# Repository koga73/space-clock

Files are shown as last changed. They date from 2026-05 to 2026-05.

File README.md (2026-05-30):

INTRODUCING THE

# SPACE CLOCK

ALWAYS RIGHT. AUTOMAGICALLY.

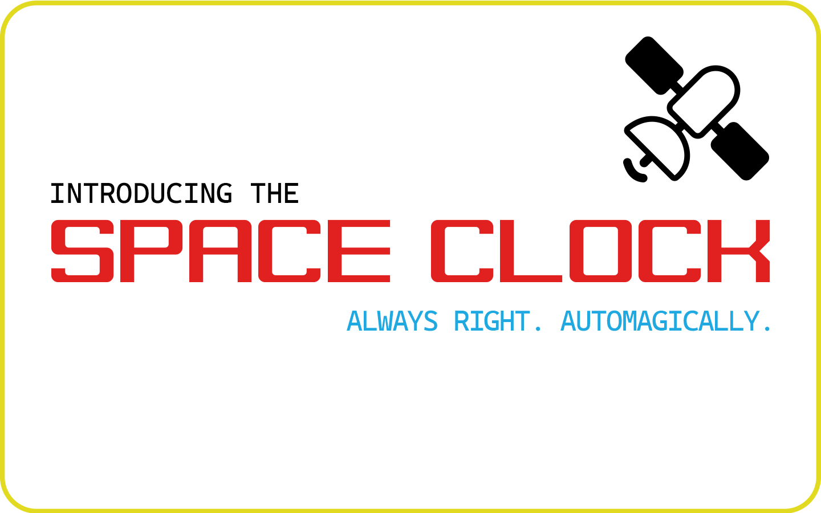
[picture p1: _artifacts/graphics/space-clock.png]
SPACE CLOCK graphic


## What is the SPACE CLOCK ?

The SPACE CLOCK sets itself using GPS signals to achieve microsecond accuracy of up to one millionth of a second. Not only is the SPACE CLOCK a physical clock, but it also acts as an __NTP__ server (network time server) allowing you to sync precise time across all of your network devices.

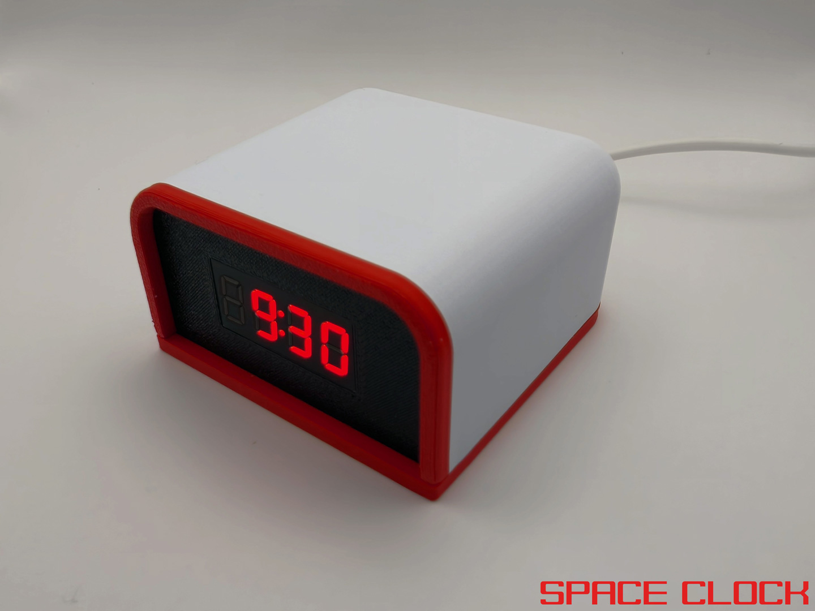
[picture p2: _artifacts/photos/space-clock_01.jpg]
SPACE CLOCK photo


## Features

- Captures `PPS (Pulse Per Second)` signal from `GPS satellites` which marks the exact start of a second
- Parses `GPS NEMA` sentences which contain data including `UTC Time`, Latitude / Longitude and more
- Built-in `NTP Server` for syncing network time
- `Web interface` with status page and configuration options __(24-hour Format, Timezone, Daylight Savings)__
- WiFi AP mode broadcasts a `hotspot` with web interface to `connect to nearby WiFi` networks
- Open-source firmware, schematics, and space-age 3D printable case

### Bill of Materials

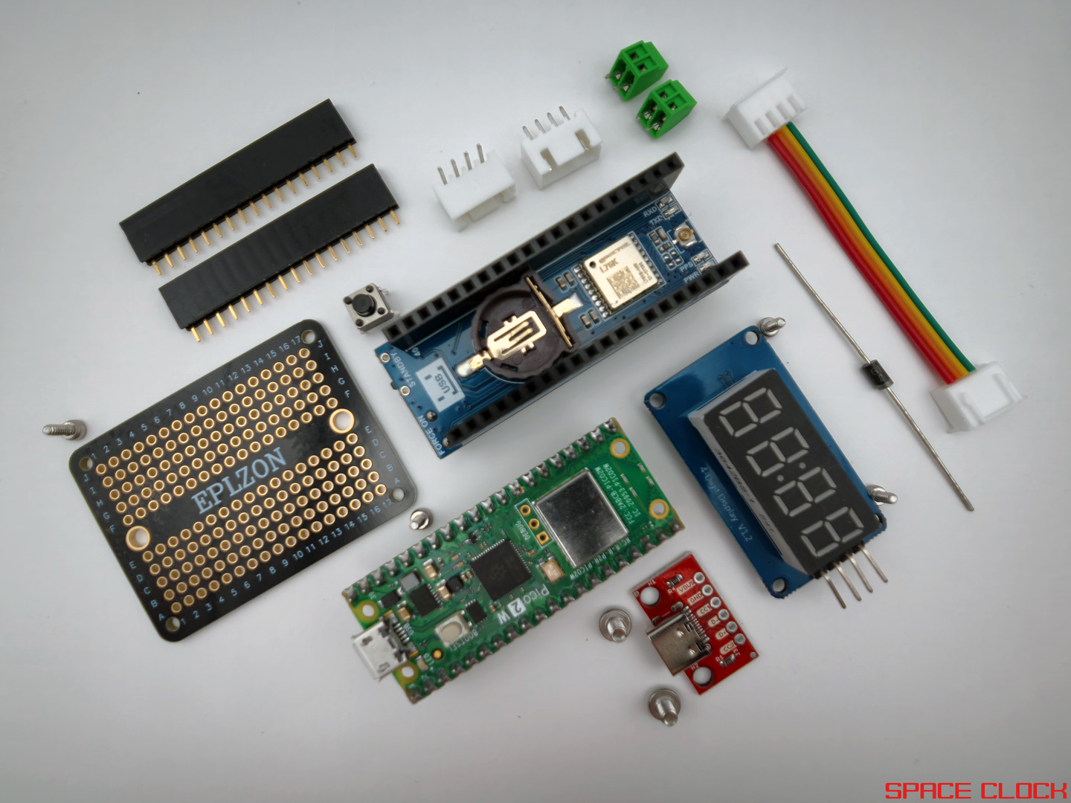
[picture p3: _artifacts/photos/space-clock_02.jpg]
SPACE CLOCK bill of materials


- [Raspberry Pi Pico 2 W](https://www.raspberrypi.com/products/raspberry-pi-pico-2/)
- [Waveshare L76K GPS module](https://www.waveshare.com/pico-gps-l76k.htm)
- [4-Digit 7-Segment display](https://www.amazon.com//dp/B0BFQNFX6D/)
- [USB-C breakout board](https://www.amazon.com/dp/B0BLSN5PR8/)
- [Solderable breadboard mini](https://www.amazon.com/dp/B09WZY8CFV/)
- [Tactile button 6x6x5mm](https://www.amazon.com/dp/B01CGMP9GY/)
- [Schottky diode 1N5817](https://www.amazon.com/dp/B07Q5H1SLY/)
- [Female headers](https://www.amazon.com/dp/B0GM834DC8/)
- [M2x4mm screws](https://www.amazon.com/dp/B0DCKDF1PD/)
- [M3x4mm screws](https://www.amazon.com/dp/B08H24W42K/)

#### Optional for GPS

- [GPS antenna](https://www.amazon.com/dp/B07Y6D76G9/) for housing internally
- [ML1220 li-ion battery](https://www.amazon.com/dp/B088KT9HB9/) for preserving ephemeris information and hot starts

## Modes

The SPACE CLOCK can operate in modes with or without a WiFi connection.

### No WiFi

First boot and when no WiFi credentials are present will simply show the current time.

1. Power via USB-C, will display `----`
2. GPS to process UTC time, will display `rising / falling animation`

> To connect to WiFI hold the bottom button for 3 seconds to reboot into AP Mode

### WiFi Mode

If WiFi credentials are available it will attempt to connect, start web/ntp servers and then display the current time.

> If WiFi fails to connect the device will reboot

1. Power via USB-C, will display `----`
2. Connect to saved wifi, will display `wave animation`
3. Successful WiFi connection will display `IP address` once
4. Start servers for web interface and ntp
5. GPS to process UTC time, will display `rising / falling animation`

> You can view the [status page](http://{IP_ADDRESS}/status) when connected via _WiFi Mode_

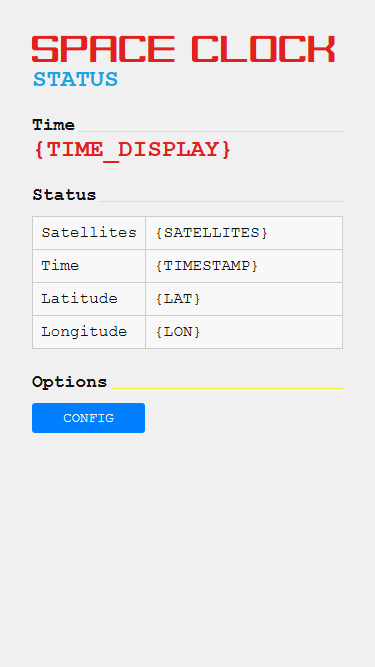
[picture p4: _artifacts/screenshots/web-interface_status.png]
SPACE CLOCK screenshot status


### AP Mode

1. Power via USB-C, will display `----`
2. Scan for nearby networks, will display `SCAN`
3. Start the AP hotspot, will display the hotspot name and start the web server
4. __You connect to the hotspot__ (`space_clock`)
5. __You navigate to the default gateway__ (http://192.168.4.1)
6. A webpage will load showing nearby WiFi networks
7. __You select a WiFi network and enter its password__
8. Device will reboot into _WiFi Mode_

> You can view the [connect to wifi page](http://192.168.4.1/connect) when connected via _AP Mode_

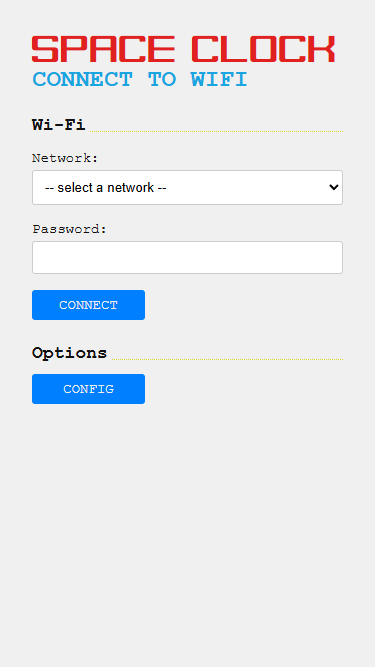
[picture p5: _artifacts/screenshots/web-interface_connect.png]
SPACE CLOCK screenshot connect


## Configuration

The SPACE CLOCK operates on UTC Time and uses the following localized defaults which can be changed:

- __24-hour format__: False
- __Timezone__: (GMT-05:00) America/New_York
- __Daylight Savings__: US/CA

> You can change these settings through the [configuration page](http://192.168.4.1/config) when connected via _WiFi Mode_ or _AP Mode_

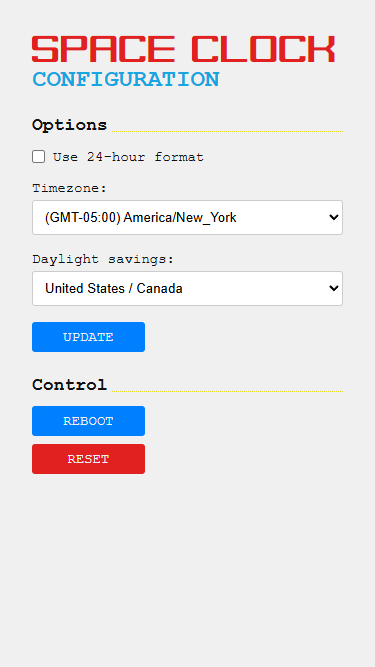
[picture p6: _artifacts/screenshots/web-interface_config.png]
SPACE CLOCK screenshot config


### 24-hour format

The SPACE CLOCK supports displaying localized time in either __12-hour AM/PM format__ or __24-hour GMT/Military format__

#### Button to change hour format

To quickly change between 12-hour / 24-hour formats just press the bottom button once

#### Web interface to change hour format

You can change this setting and more through the web interface when connected via _WiFi Mode_ or _AP Mode_.

### Timezone

GPS satellites transmit time in UTC, as such you can change the localized timezone.

#### Web interface to change TZ

_Timezone_ can be set through the following selections in the web interface:

- (GMT-10:00) Pacific / Honolulu
- (GMT-09:00) America / Anchorage
- (GMT-08:00) America / Los_Angeles
- (GMT-07:00) America / Denver
- (GMT-06:00) America / Chicago
- (GMT-05:00) America / New_York
- (GMT-03:00) America / Sao_Paulo
- (GMT+00:00) UTC / Europe / London
- (GMT+01:00) Europe / Paris
- (GMT+02:00) Africa / Cairo
- (GMT+04:00) Asia / Dubai
- (GMT+09:00) Asia / Tokyo
- (GMT+10:00) Australia / Sydney
- (GMT+12:00) Pacific / Auckland

### Daylight savings

GPS satellites transmit time in UTC, as such you can apply Daylight Savings with regional rules.

#### Web interface to change DST

_Daylight Savings_ rules can be applied through the following selections in the web interface:

- __United States / Canada__
	- Starts on second Sunday of March at 2am
	- Ends on first Sunday of November at 2AM
- __United Kingdom / European Union__
	- Starts on last Sunday of March at 1AM
	- Ends on last Sunday of October at 2AM
- __Australia__
	- Starts on first Sunday of October at 2am
	- Ends on first Sunday of April at 3AM

### Reboot

You can reboot the device by clicking the "__Reboot__" button in the web interface.

### Reset

You can factory reset the device by clicking the "__Reset__" button in the web interface. This will delete your preferences and reset the device back to defaults.

## Build your own!

This project can be built for around ~$50 at the time of writing

### Schematic

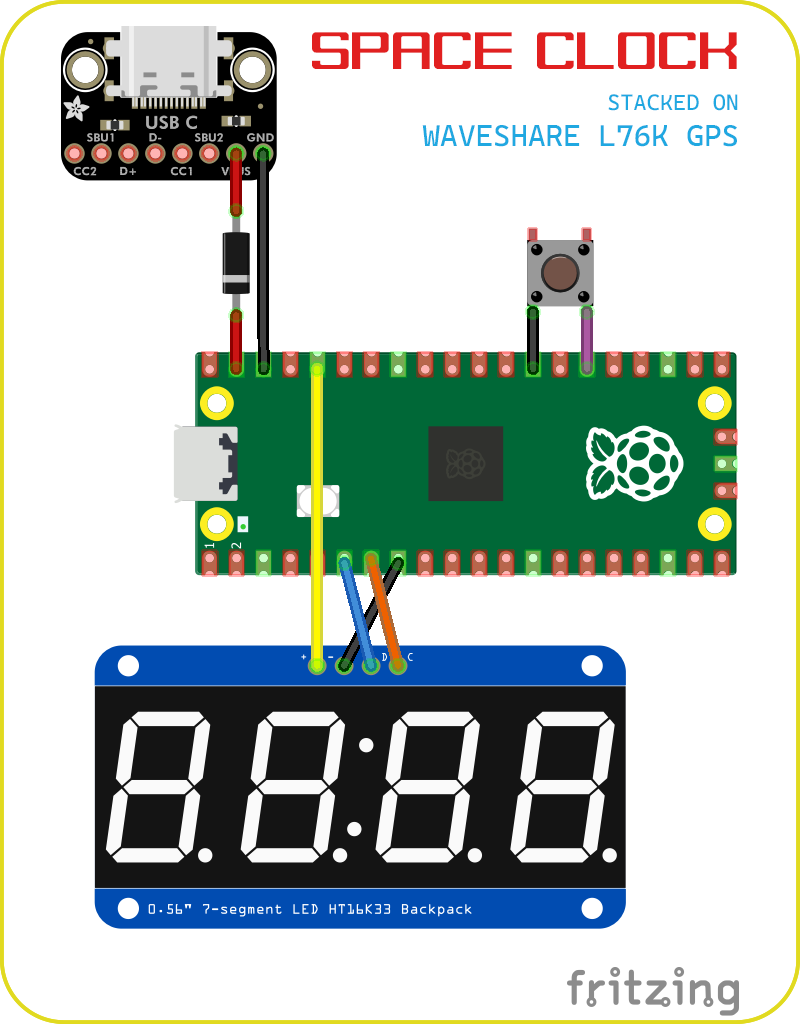
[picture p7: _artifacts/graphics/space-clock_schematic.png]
SPACE CLOCK schematic


### Enable PPS on the Waveshare L76K

For the most accurate time, there is a small modification needed to the _Waveshare L76K_ board which enables a PPS (Pulse Per Second) signal interrupt on `Pin 16`.

Follow the directions included in Waveshare's documentation, but essentially on the back of the board you just need to solder a `0Ω ohm resistor` or wire across the pads for `R20`.

### Raspberry Pi Pico 2 W

The firmware is written in MicroPython, as such you will need to follow the [instructions on flashing the MicroPython](https://www.raspberrypi.com/documentation/microcontrollers/micropython.html#what-is-micropython) runtime.

Then follow the guide to [Install dependencies and official VSCode extension](https://www.raspberrypi.com/news/get-started-with-raspberry-pi-pico-series-and-vs-code/)

To upload the code to the Pico through VSCode just open the command palette (CTRL + SHIFT + P) and select `MicroPico: Upload project to Pico`

### Power via USB-C breakout board

I wanted the ability to power the Pico via a USB-C breakout board and it was easy enough. Just connect the VBUS/VCC + GND on the breakout board to VSYS on the Pico `Pin 39` and GND to `Pin 38`

> You should put a Schottky Diode between external power and VSYS to prevent issues if powered via Micro-USB and Externally at the same time

### Display

Since this is a clock, the good ole 4-digit 7-segment display makes sense!

Wiring:
- Display GND to Pico GND `Pin 8`
- Display VCC to Pico 3v3(OUT) `Pin 36`
- Display DIO to Pico I2C0 SDA `Pin 6`
- Display CLK to Pico I2C0 SCL `Pin 7`

> On my solderable breadboard I connected row 36 with row 5. On the female header I removed the pin on row 5. This allows for the 3V3(OUT) to be next to the other pins 6/7/8 needed for display.

### Button

The button on the bottom allows for short presses such as to change between 12-hour / 24-hour format as well as long holds to toggle reboot of modes WiFi / AP

One leg of the button should go to GND `Pin 13` / `Pin 28` and the other leg should attach to GP20 `Pin 26`

### 3D printed case

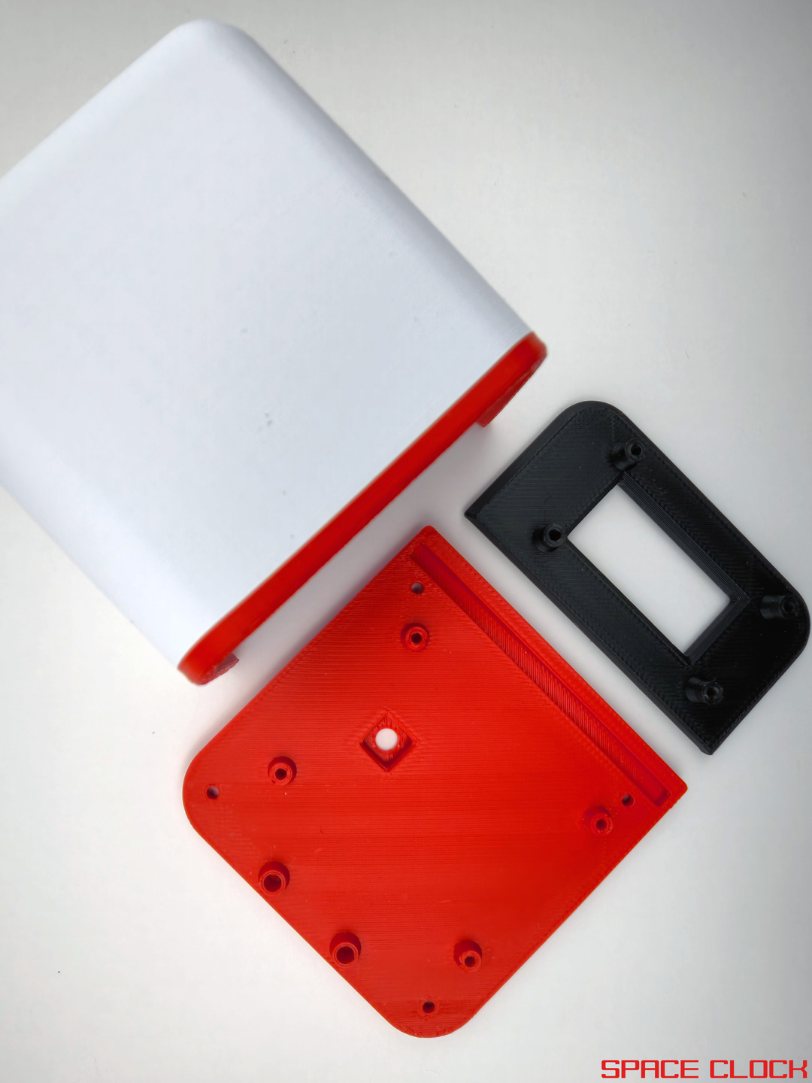
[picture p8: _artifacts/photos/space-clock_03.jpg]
SPACE CLOCK 3d printed case


The case consists of three parts, the display mount, the bottom plate and the top cover.

- Print in PLA with or without infill.
- Print top cover vertically with support

Use the appropriate M2/M3 screws listed in the bill-of-materials to mount the boards to the respective case pieces.

#### SMA connector

Inside the case cover is a pre-formed 0.25in cutout for an SMA connector if you want an external GPS antenna just can drill this out with a 0.25in forstner drill bit.

If you do not want an external GPS antenna you can place a small ceramic GPS antenna internally. I stuck mine to the backside of the female headers with 3M VHB tape.

### Assembly

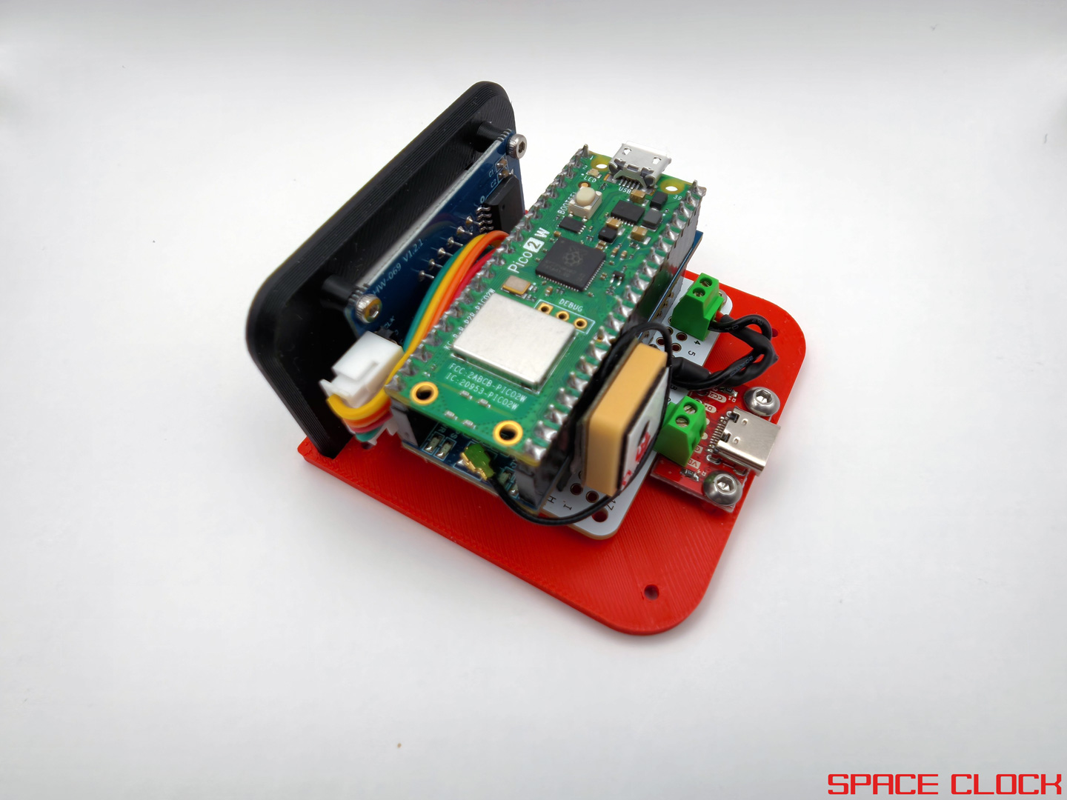
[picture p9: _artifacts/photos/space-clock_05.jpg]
SPACE CLOCK inner back


Solder connections on the mini solderable breadboard as specified. Connect the USB-C breakout board and Display as specified. Plug the Waveshare L76K into the solderable breadboard female headers and then the Pico into the Waveshare female headers

### Post your build!

If you make your own I would love to see it, post as a make or remix!

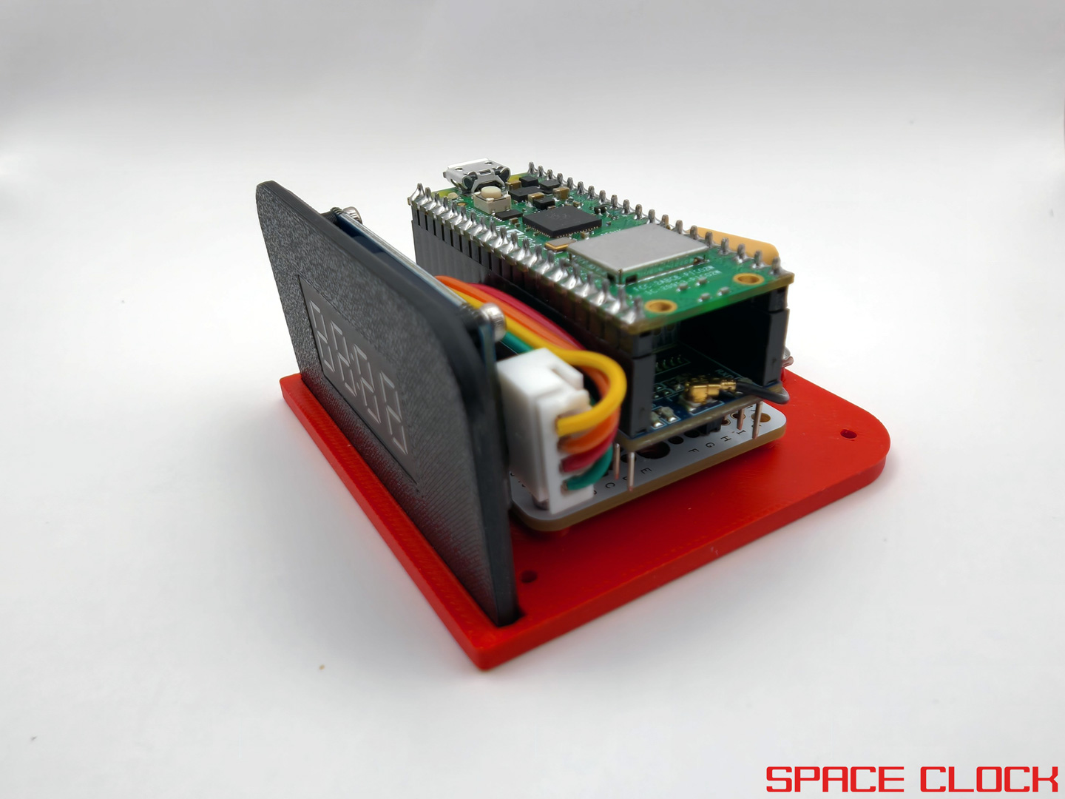
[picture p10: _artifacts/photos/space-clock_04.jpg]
SPACE CLOCK inner front


## Future plans

- Automatically select Timezone and Daylight Savings via Latitude / Longitude coordinates
  - Challenges with testing point in polygon timezone / region / country / state with resolutional accuracy and data size limits

## Thingiverse x Raspberry Pi

This is my entry for the [#PicoBuilders](https://challenges.thingiverse.com/pico-builders) challenge hosted by [Thingiverse](https://thingiverse.com) in collaboration with the [Rasperry Pi Foundation](https://www.raspberrypi.org/)

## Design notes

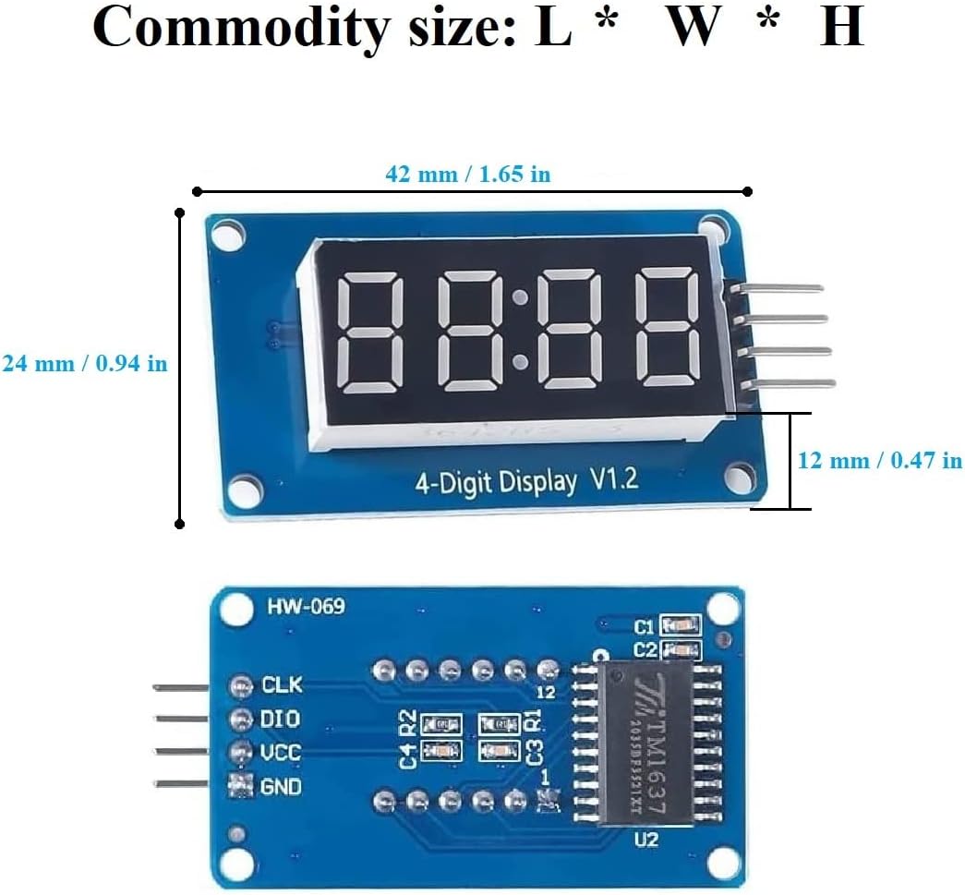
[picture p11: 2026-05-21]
_artifacts/specs/spec_4-digit-7-segment.jpg

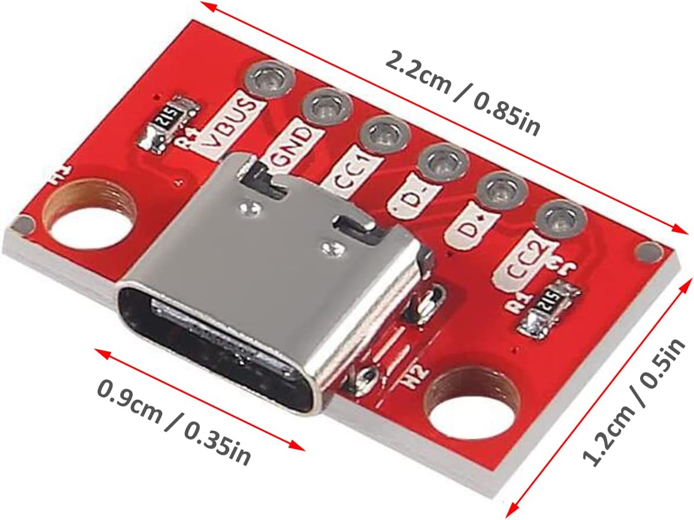
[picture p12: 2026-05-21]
_artifacts/specs/spec_usb-c-breakout.jpg

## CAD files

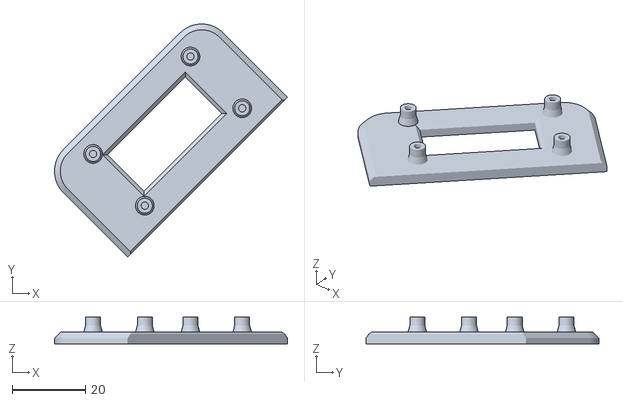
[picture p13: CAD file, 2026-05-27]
_artifacts/models/space-clock_case-face.stl
63.7 x 63.7 x 7.30

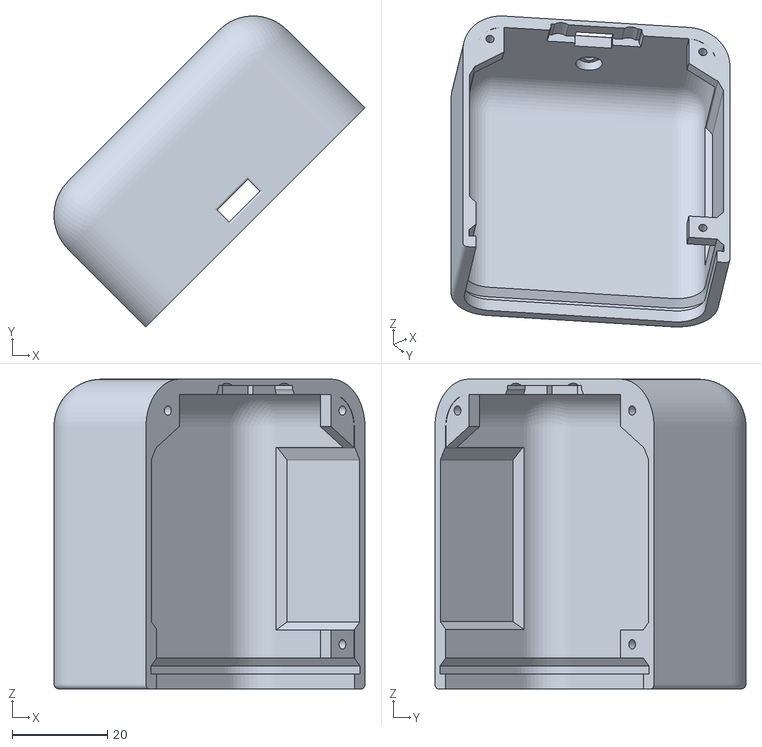
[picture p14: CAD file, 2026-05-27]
_artifacts/models/space-clock_case-top.stl
65.3 x 65.3 x 65.0

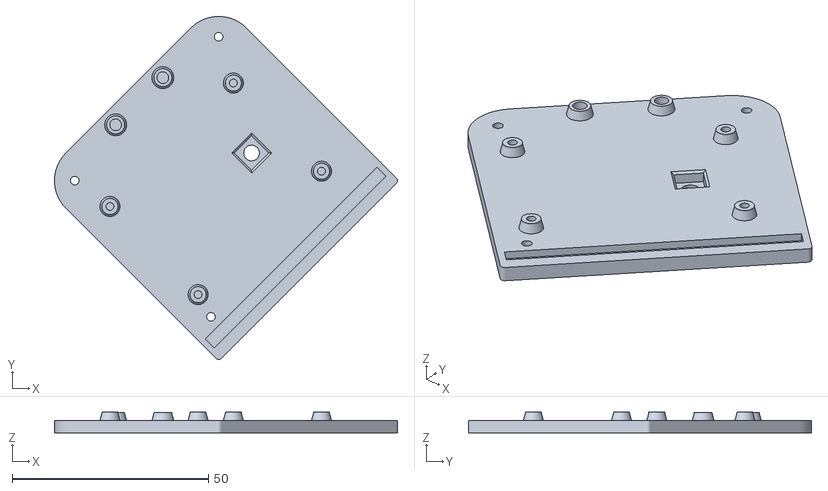
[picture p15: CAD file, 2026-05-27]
_artifacts/models/space-clock_case-bottom.stl
87.4 x 87.4 x 5.34

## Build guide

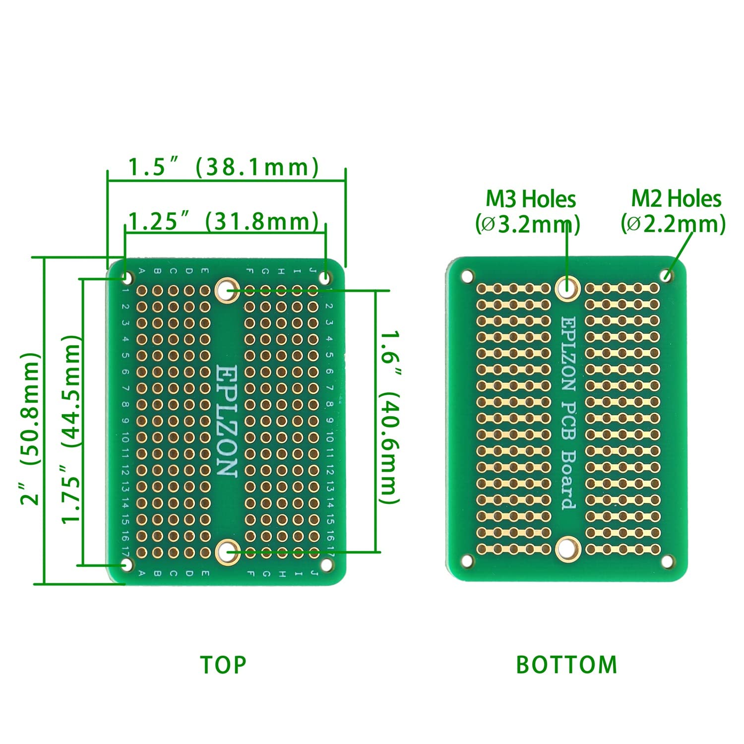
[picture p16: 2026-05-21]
_artifacts/specs/spec_eplizon-solderable-breadboard.jpg

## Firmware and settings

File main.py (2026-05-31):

import time
import asyncio
import machine
import network
import _thread
from machine import Pin

from src.filesystem import boot_read, wifi_read, settings_read
from src.wifi import wlan_reset, wlan_scan, wlan_ap, wlan_connect
from src.button import Button
from src.display import Display
from src.server import web_server, handle_request_gateway, handle_request_status

from src.clock import Clock
from src.gps import GPS
from src.ntp import NtpServer

AP_SSID = "space_clock"
AP_PASS = None

WIFI_HOSTNAME = "space-clock"
DEFAULT_WIFI = {
    "ssid": None,
    "password": None
}

STATUS_DELAY = 15000

# region GLOBALS
clock = Clock.get_instance()
gps = GPS(16)
display = Display(Pin(5), Pin(4), Pin("LED", Pin.OUT))
button = Button(20)
# endregion

# region MODE_DEFAULT
async def mode_default():
    print("\nmode_default")

    # See if we have settings saved
    print("\nsettings")
    f24hr, tz, dst = settings_read()
    clock.set_locale(f24hr, tz, dst)
    
    # See if we should connect to wifi
    print("\nwifi")
    ssid = DEFAULT_WIFI["ssid"]
    password = DEFAULT_WIFI["password"]
    file_ssid, file_password = wifi_read()
    if (file_ssid != None):
        ssid = file_ssid
    if (file_password != None):
        password = file_password

    server = None
    if (ssid != None and ssid != ""):
        display.show("_-^-_-^-_")
        
        # Connect to wifi
        wlan = await wlan_connect(ssid, password)
        ip = wlan.ifconfig()[0]
        
        # Start web server
        server = await web_server(
            lambda request: _handle_request(request, ip),
            _reboot
        )

        # Show IP address on display once
        await display.show_async(ip.replace(".", "_"), loops = 1)
    
    # Main loop for GPS and display
    await _loop_default()

    # Clean up
    if (server != None):
        server.close()

def _handle_request(request, ip):
    satellites = gps.get_satellites()
    time_display = clock.get_display()
    timestamp_utc = clock.get_timestamp()
    timestamp_local = clock.get_timestamp_local()
    lat = gps.get_lat()
    lon = gps.get_lon()
    altitude = gps.get_altitude()
    height = gps.get_height()
    
    return handle_request_status(request, {
        "ip": ip,
        "satellites": satellites,
        "time_display": time_display,
        "timestamp_utc": timestamp_utc,
        "timestamp_local": timestamp_local,
        "lat": lat,
        "lon": lon,
        "altitude": altitude,
        "height": height
    })
#endregion

# region LOOP_DEFAULT
async def _loop_default():
    print("\nloop default")
    display.show("^^^^----____----^^^^")
    
    last_status_time = 0
    while True:
        now_ms = time.ticks_ms()

        # If our check button function returns true, break
        if (button.loop_button(now_ms, button.default_released, button.default_held)):
            break
        
        # Periodic status update
        colon = True
        if (time.ticks_diff(now_ms, last_status_time) > STATUS_DELAY):
            last_status_time = now_ms
            colon = False

            print("\ngps status")
            if (gps.has_fix()):
                print(f"time = {gps.get_timestamp()}")
                print(f"lat = {gps.get_lat()}, lon = {gps.get_lon()}")
                print(f"satellites = {gps.get_satellites()}")
            else:
                print("searching for satellites...")
            
        # Display
        _display_current_time(colon)

        # Tick
        await asyncio.sleep_ms(100)
# endregion

# region DISPLAY
def _display_current_time(colon = True):
    if (clock._time_us == 0):
        return
    text = clock.get_display()

    display.show(text, colon = colon)
# endregion

# region MODE_AP
async def mode_ap():
    print("\nmode_ap")

    display.show("SCAN")
    networks = await wlan_scan()

    display.show("HOST")
    ap = await wlan_ap(AP_SSID, AP_PASS)
    ip = ap.ifconfig()[0]

    server = await web_server(
        lambda request: handle_request_gateway(request, {
            "title": "Connect to WiFi",
            "networks": networks,
            "ip": ip
        }),
        _reboot
    )

    display.show(AP_SSID)

    # Main loop for AP
    await _loop_ap()

    server.close()
# endregion

# region LOOP_AP
async def _loop_ap():
    print("\nloop ap")

    while True:
        # If our check button function returns true, break
        if (button.loop_button(time.ticks_ms(), button.ap_released, button.ap_held)):
            break

        await asyncio.sleep_ms(250)
# endregion

# region GPS_NTP
def _loop_gps():
    gps.init()

    # Start the ntp server
    ntp = NtpServer(clock.get_seconds)
    ntp.start()
    
    while True:
        # Process NTP requests
        break_flag = ntp.udp_loop()
        if (break_flag):
            break

        # Try to receive GPS data on PPS signal
        did_update = gps.loop()
        
        # If we have a new GPS timestamp, update the clock and display
        if (did_update):
            # Update Clock with GPS time on PPS signal
            datetime = gps.get_datetime()
            # Update our custom clock
            clock.set_datetime(datetime, gps.get_pps())
    
    print("gps and ntp stopped")
    ntp.stop()
# endregion

# region MAIN
async def main():
    print("starting...")
    # Add delay to allow for stopping the program if needed
    await asyncio.sleep_ms(2000)

    # Start display loop
    asyncio.create_task(display.loop())
    display.show("----")

    # Start GPS in a separate thread
    _thread.start_new_thread(_loop_gps, ())

    # Reset wlan interfaces
    await wlan_reset()
    network.hostname(WIFI_HOSTNAME)

    try:
        mode = boot_read()
        if (mode == "ap"):
            await mode_ap()
        else:
            await mode_default()
    except RuntimeError as err:
        print(err)
    
    await _reboot()

async def _reboot():
    await asyncio.sleep_ms(1000)
    print("rebooting...")
    display.show("    ")
    machine.soft_reset()
# endregion

try:
    asyncio.run(main())
except KeyboardInterrupt:
    print("\nstopped by user")
    display.show("    ")

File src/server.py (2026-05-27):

import asyncio
import machine
import re

from src.clock import Clock
from src.filesystem import boot_write, wifi_write, settings_read, settings_write, delete_all

# region HTTP_STATUS
STATUS_OK_HTML = "HTTP/1.0 200 OK\r\nContent-type: text/html\r\n\r\n"
STATUS_OK_CSS = "HTTP/1.0 200 OK\r\nContent-type: text/css\r\nCache-Control: public, max-age=21600\r\n\r\n"
STATUS_OK_TTF = "HTTP/1.0 200 OK\r\nContent-type: font/ttf\r\nCache-Control: public, max-age=21600\r\n\r\n"

STATUS_BAD_REQUEST = """HTTP/1.1 400 Bad Request
Content-Type: text/plain
\r\n
"Bad Request"
"""
STATUS_NOT_FOUND = """HTTP/1.1 404 Not Found
Content-Type: text/plain
\r\n
"Not Found"
"""
# endregion

# region WEB_SERVER
# Handle incoming HTTP requests and send to the appropriate handler
async def web_server(request_handler, reboot_handler = None):
    print("\nweb_server")

    server = await asyncio.start_server(
        lambda r, w: handle_client(r, w, request_handler, reboot_handler),
        "0.0.0.0",
        80
    )
    return server

async def handle_client(reader, writer, request_handler, reboot_handler = None):
    request = await _read_http_request(reader)
    print("\nhttp request:\n" + str(request))

    response, reboot = await request_handler(request)
    
    if isinstance(response, bytes):
        writer.write(response)
    else:
        writer.write(response.encode())
    
    await writer.drain()
    writer.close()
    await writer.wait_closed()

    # Reboot
    if (reboot == True):
        if (reboot_handler != None):
            await reboot_handler()
#endregion

# region GATEWAY_ROUTES
async def handle_request_gateway(request, template_data):
    ip = template_data["ip"]
    networks = template_data["networks"]

    verb, path = _get_verb_path(request)
    print("\n", verb, path)

    # GET /
    if (path == "/"):
        with open("static/index.html", "r") as f:
            html = f.read()
        html = html.replace("{IP_ADDRESS}", ip)
        html = html.replace("{DESTINATION}", "connect")

        response = STATUS_OK_HTML
        response += html
        return response, False

    # GET /connect
    elif (verb == "GET" and path == "/connect"):
        options = "\n".join([f'<option value="{n["ssid"]}">{n["ssid"]}</option>' for n in networks])
        
        with open("static/connect.html", "r") as f:
            html = f.read()
        html = html.replace("{IP_ADDRESS}", ip)
        html = html.replace("{BODY_CLASS}", "state-default")
        html = html.replace("{WIFI_OPTIONS}", options)

        response = STATUS_OK_HTML
        response += html
        return response, False

    # POST /connect
    elif (verb == "POST" and path == "/connect"):
        # Parse params from body
        body = _get_body(request)
        param_ssid = _get_param(body, "ssid")
        param_password = _get_param(body, "password")

        # Ensure required params are present
        if (param_ssid == None or param_password == None):
            response = STATUS_BAD_REQUEST
            response += "Missing required parameters"
            return response, False
        # Validate params
        if (not bool(re.search(r"^[a-zA-Z0-9_ \.\-]+$", str(param_ssid)))):
            response = STATUS_BAD_REQUEST
            response += "Invalid ssid"
            return response, False
        if (not len(str(param_password)) >= 8):
            response = STATUS_BAD_REQUEST
            response += "Invalid password"
            return response, False
        
        # Write wifi credentials to file
        wifi_write(param_ssid, param_password)
        # Set boot mode to default
        boot_write("default")

        # Return HTML
        with open("static/connect.html", "r") as f:
            html = f.read()
        html = html.replace("{IP_ADDRESS}", ip)
        html = html.replace("{BODY_CLASS}", "state-reboot")

        response = STATUS_OK_HTML
        response += html
        return response, True

    # Try shared routes
    else:
        return handle_request_shared(request, template_data)
# endregion

# region STATUS_ROUTES
async def handle_request_status(request, template_data):
    ip = template_data["ip"]
    
    satellites = template_data["satellites"]
    
    time_display = template_data["time_display"]
    time_display = f"{time_display[0:2]}:{time_display[2:4]}"
    timestamp_utc = template_data["timestamp_utc"]
    timestamp_local = template_data["timestamp_local"]

    lat = template_data["lat"]
    lon = template_data["lon"]
    altitude = template_data["altitude"]
    height = template_data["height"]
    
    verb, path = _get_verb_path(request)
    print("\n", verb, path)

    # GET /
    if (path == "/"):
        with open("static/index.html", "r") as f:
            html = f.read()
        html = html.replace("{IP_ADDRESS}", ip)
        html = html.replace("{DESTINATION}", "status")

        response = STATUS_OK_HTML
        response += html
        return response, False

    # GET /status
    elif (path == "/status"):
        with open("static/status.html", "r") as f:
            html = f.read()
        html = html.replace("{IP_ADDRESS}", ip)
        html = html.replace("{SATELLITES}", str(satellites))
        html = html.replace("{TIME_DISPLAY}", time_display)
        html = html.replace("{TIMESTAMP_UTC}", timestamp_utc)
        html = html.replace("{TIMESTAMP_LOCAL}", timestamp_local)
        html = html.replace("{LAT}", str(lat))
        html = html.replace("{LON}", str(lon))
        html = html.replace("{ALTITUDE}", str(altitude))
        html = html.replace("{HEIGHT}", str(height))

        response = STATUS_OK_HTML
        response += html
        return response, False
    
    # Try shared routes
    else:
        return handle_request_shared(request, template_data)
# endregion
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

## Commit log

2026-05-09 broke display methods out to their own class and async task
    [display.py, main.py, server.py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]
2026-05-13 wired up button to change modes between default and access point
2026-05-14 wiring up dst, tz and microsecond accuracy, wip
2026-05-21 changed pins for matching on soldered board
2026-05-23 fixed and confirmed accuracy
    [clock.py, gps.py, main.py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]
2026-05-25 added schematic
    [space-clock.fzz]
2026-05-25 adjusted schematic image
2026-05-27 added case stl files
    [space-clock_case-bottom.stl, space-clock_case-face.stl, space-clock_case-top.stl]
2026-05-28 added script to compare a sample ntp server against a reference
2026-05-28 fixed accuracy for real this time and verifiable
    [clock.py, gps.py, main.py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]
2026-05-28 fixed a typo and added check for large delta to not affect jitter
    [gps.py]
2026-05-30 ntp error handling if no satellites to not show time
    [clock.py, main.py, ntp.py]
2026-05-31 moved gps processing and ntp server to a separate thread
2026-05-31 fixed thread locks
